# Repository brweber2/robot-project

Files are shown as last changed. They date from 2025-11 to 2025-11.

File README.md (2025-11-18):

# robot-project

Documentation for robot build out (hardware and software).

## Books

This is a mix of various open source projects and a couple of books.

* [Build Your Own Robot: Using Python, CRICKIT, and Raspberry PI](https://www.amazon.com/Build-Your-Own-Robot-Raspberry/dp/1633438457)
  * NOTE: that this project does NOT use a CRICKIT but this book is a good starting point to learn robotics concepts
* [Make: Robotic Arms](https://www.amazon.com/Make-Robotic-Arms-Matthew-Eaton/dp/1680458434)
  * code on GITHUB: https://github.com/ACBRrobotics/Make_Robotic_Arms
* [ROS 2 From Scratch](https://www.amazon.com/ROS-Scratch-started-robotics-applications/dp/B0DJCFC29Q)

## General Notes

### Utilities

* [Convert DXF files to STL](https://imagetostl.com/convert/file/dxf/to/stl)

### Tools Required

You do not need the specific tools linked, I've just included them for convenience.

* 3D Printer [FLASHFORGE Adventurer 5M](https://www.amazon.com/dp/B0CPSZ9PGS)
  * 3D Printing Slicer [Orca Slicer](https://orca-slicer.com/)
* PLA Filament [Rapid PLA Filament 1.75mm Ruby Red](https://www.amazon.com/dp/B0CB7TW3XC)
* Screwdriver [JOREST Precision Screwdriver Set](https://www.amazon.com/dp/B0D2HGJFL2)
* Heat Gun [SEEKONE Heat Gun](https://www.amazon.com/dp/B086WH19WH)
* Soldering Iron [Soldering Iron](https://www.amazon.com/gp/product/B0BX2N258S)
* M5 Hex Wrench [M5 Hex Wrench is 4mm](https://www.amazon.com/Amazon-Basics-Wrench-Standard-26-Piece/dp/B0776C2D6H)
* Soldering Mat [Soldering Mat](https://www.amazon.com/Kaisi-Insulation-Soldering-Maintenance-Electronics/dp/B073RFB6BX)

#### Software Used

* [Orca Slicer](https://orca-slicer.com/)
* [Arduino IDE](https://www.arduino.cc/en/software/)
* [ROS 2](https://www.ros.org/)

## Hardware

Much of this is from existing open source files. They are linked whenever a file was included.

### Chassis

[Chassis](CHASSIS.md)

### Wheels

[Wheels](WHEEL.md)

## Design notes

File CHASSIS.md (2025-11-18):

### Chassis

Much of this is from [Hugging Face's Lerobot](https://huggingface.co/docs/lerobot/lekiwi)

#### Non-3D Printed Parts

* Motor (3 total) [12V 37mm Motor](https://www.amazon.com/dp/B08D3SSG55)
* AWG Plug Connector [AWG Plug Connector](https://www.amazon.com/dp/B06XRBKSY2)
* Wire Heat Shrink Tubing [Wire Heat Shrink Tubing](https://www.amazon.com/dp/B0BG6V4HV4)
* Microcontroller
  * Coming soon

#### 3D Printed Parts

* Base Plate (2 total) [Base Plate](3d_prints/chassis/base_plate_layer2.stl) 
  * Source: [LeKiwi Base Plate](https://github.com/SIGRobotics-UIUC/LeKiwi/blob/main/3DPrintMeshes/base_plate_layer2.stl)
* Motor Mount (3 total) [Motor Mount](3d_prints/chassis/Marcin-61-JGB37-3650_holder.3mf) 
  * Source: [Motor Mount](https://openroboticplatform.com/part:61)
* Microcontroller Mount
  * Coming soon
* Power Source Mount
  * Coming soon

#### Assembly

Coming soon...

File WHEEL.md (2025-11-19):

### Wheels

This project uses 3 3d printed mecanum wheels.

As a starting point I used this project:
[Mecanum wheel 3d print model](https://www.thingiverse.com/thing:6175379)

#### Non-3D Printed Parts

* 693 ball bearing (24 per wheel - 72 total) (3x8x4 mm) [693 Ball Bearing](https://www.amazon.com/dp/B0DHCLF9S3)
* M3 threaded rods (12 per wheel - 36 total) 75mm long [M3 Threaded Rods](https://www.amazon.com/dp/B0D4QMWM4H)
* M3 lock nuts (24 per wheel - 72 total) [M3 Lock Nuts](https://www.amazon.com/dp/B0DFY8Y1TK)
* M3 washers (24 per wheel - 72 total) [M3 Washers](https://www.amazon.com/dp/B0B3RVM92N)
* M5 heat set threaded inserts (12 per wheel - 36 total) [M5 Heat Set Threaded Inserts](https://www.amazon.com/dp/B07YSVXWS8)
* M4 × 90mm bolts (5 per wheel - 15 total) [M4 90mm bolts](https://www.amazon.com/dp/B0DYN68HJH)
* M4 nuts (5 per wheel - 15 total) (or nylock nuts to prevent loosening) [M4 Lock Nuts](https://www.amazon.com/Vifmy-M4-0-7mm-Nuts%EF%BC%8C304-Stainless-Locknuts%EF%BC%8CStandard/dp/B0CPJCXPLJ?th=1)
* M4 washers (10 per wheel - 30 total) [M4 Washers](https://www.amazon.com/Litoexpe-Stainless-Outside-Diameter-Thickness/dp/B0BGLB6DD2)
* 20mm Heat Shrink Tubing (4 foot rolls - 2 total for 3 wheels) [Heat Shrink Tubing](https://www.amazon.com/dp/B0B616KF8J)
* M5 Screws (12 per wheel - 36 total) [M5 12mm Screws](https://www.amazon.com/iexcell-Thread-Socket-Button-Screws/dp/B0CTH2YHQ5)

#### 3D Prints

These links are the STL files. There are source files available in [3D Prints](3d_prints) if you need to make adjustments on your own.

There was no way to connect the wheel to the motor so I had Claude Code generate two adapter pieces, one for each side of the wheel. Through trial and error I found that the back plate should be 64.5mm in diameter.

Our robot is round and uses 3 wheels.

* [Rim](3d_prints/wheel/RIM.stl) 1 / wheel, 3 total.
* [Left Side](3d_prints/wheel/side_L.stl) 2 / wheel. 2 total.
  * NOTE: The STL file on thingiverse has 5 holes which does NOT match the 6 holes on the Rim and on the Right side. I've inverted the right side to make a left side with 6 holes and that is the link I provide here.
* [Right Side](3d_prints/wheel/side_R.stl) 2 / wheel. 4 total.
* [Torque Cap](3d_prints/wheel/leo_rover_torque_plate.stl) 1 / wheel. 3 total.
* [Roller](3d_prints/wheel/Roller.stl) 12 / wheel. 36 total.
  * NOTE: The original source says that if you use heat shrink tubing (which we do) you should use the thinner rollers. This lead to the frame making contact with the ground so we use heat shrink tubing on the standard rollers instead.
* [Adapter For Torque Cap Side](3d_prints/wheel/mecanum_front_plate.stl) 1 / wheel. 3 total.
* [Adapter For Back Side](3d_prints/wheel/mecanum_back_plate_64.5mm.stl) 1 / wheel. 3 total.

##### Wheel Assembly

For additional diagrams see the source project on [Thingiverse](https://www.thingiverse.com/thing:6175379)

* 3D print the parts - please note that this will take quite some time. 
  * 3 rims
  * 2 side right
  * 1 side left
  * 3 torque caps
  * 3 adapter front
  * 3 adapter back
  * 36 rollers
* Use soldering iron to put the heat set threaded inserts into the rim. Here is a helpful video on [how to use heat set threaded inserts](https://youtube.com/shorts/JnhZDiwrd0g?si=wym4r56KDjHzZoVA)
* Prepare the rollers
  * Put a 693 ball bearing in each end of the roller. I find that putting the ball bearing on the table and pushing down the roller works best to pop them into place.
  * Cut the heat shrink tubing into 36 pieces that are 55mm long
  * Wrap each roller in the heat shrink tubing
  * Use the heat gun to shrink the tubing around each roller. Do not over heat or the 3d printed roller will melt too.
* Put the wheel together (this describes the steps for ONE wheel - you will need to build THREE wheels)
  * Do this 12 times
    * Put one end of the 75mm rod through a hole in the side (left or right)
    * screw in a M3 lock nut on the outside
    * add a washer on the inside
    * slide the roller into the 75mm rod - it should fit nicely through the ball bearings in the roller
    * add a washer to the other end of the roller
  * Place the rim in the middle of the side (left or right)
  * Add a matching side piece (if using side right then side right, if using side left the another side left)
    * Do this 12 times
      * one roller at a time pass the rod through a whole in the side
      * add a M3 lock nut
  * secure the rim to the sides using M5 12mm screws. Be sure to secure it to both sides.
  * slide the torque cap into the rim (it will only fit on the side with grooves)
  * Use the 90mm bolts and M4 lock nuts to fasten the front adapter to the torque cap and the back adapter (which goes on the opposite side as the torque cap). The front adapter has a hole in the middle for the motor's d-shaft and is smaller in diameter than the back adapter.
  I put the nuts in the back adapter and the bolts through the front adapter. Once the bolts are in the recessed holes in the front adapter use a M4 allen wrench to tighten them.

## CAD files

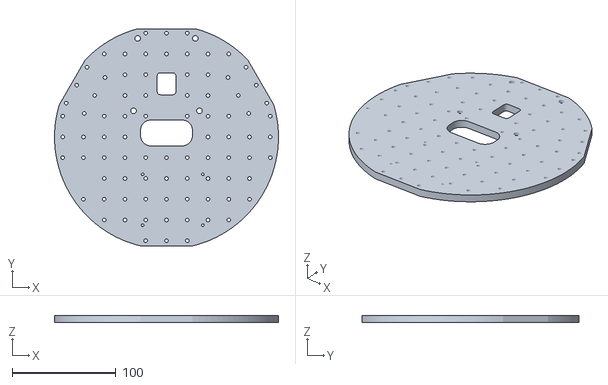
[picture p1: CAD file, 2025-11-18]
3d_prints/chassis/base_plate_layer2.stl
215.9 x 209.0 x 7.00

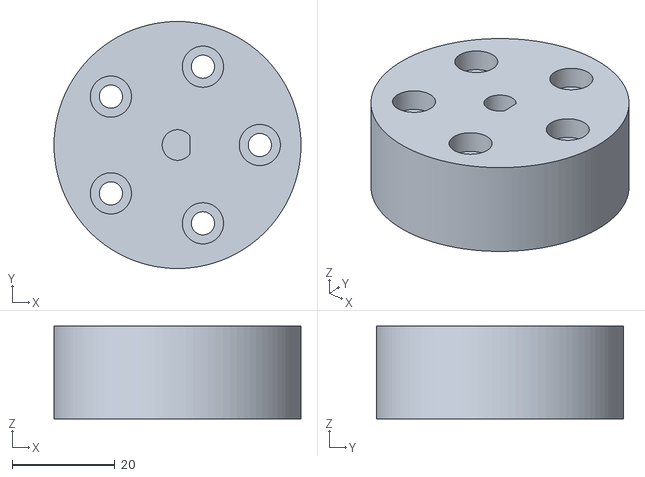
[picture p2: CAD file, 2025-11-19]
3d_prints/wheel/mecanum_front_plate.stl
48.0 x 48.0 x 18.0

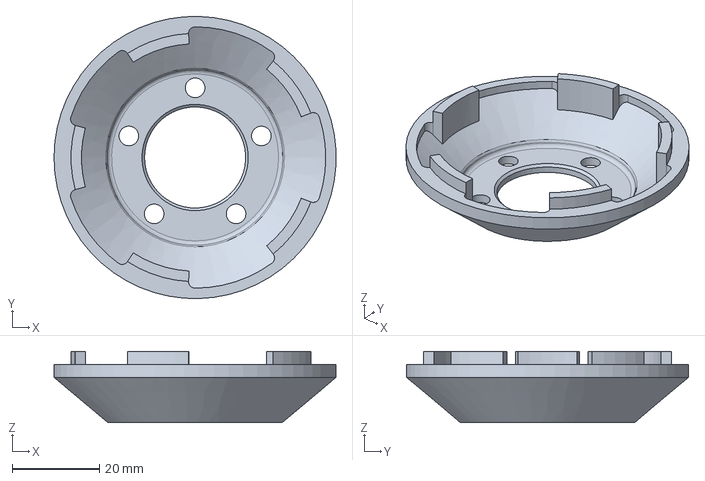
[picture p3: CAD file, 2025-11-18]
3d_prints/wheel/leo_rover_torque_plate.step
64.8 x 64.8 x 16.4 mm

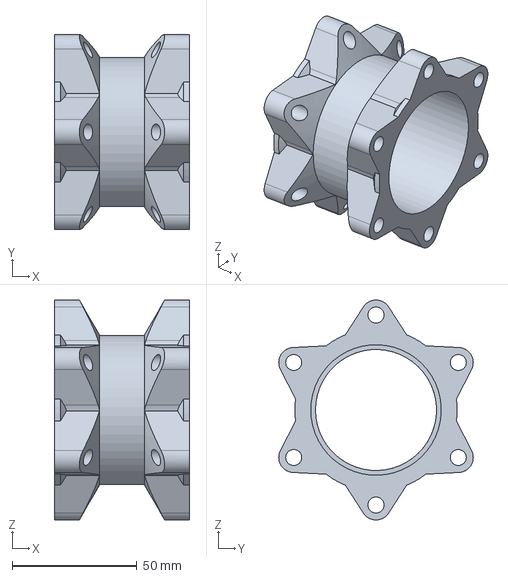
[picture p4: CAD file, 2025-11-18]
3d_prints/wheel/rim.step
54.1 x 77.8 x 88.0 mm

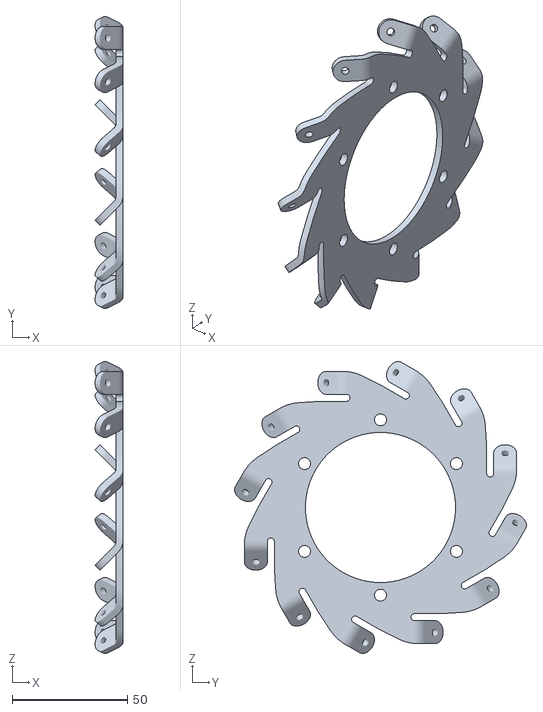
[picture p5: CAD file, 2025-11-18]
3d_prints/wheel/side_L.stl
12.1 x 126.5 x 126.5

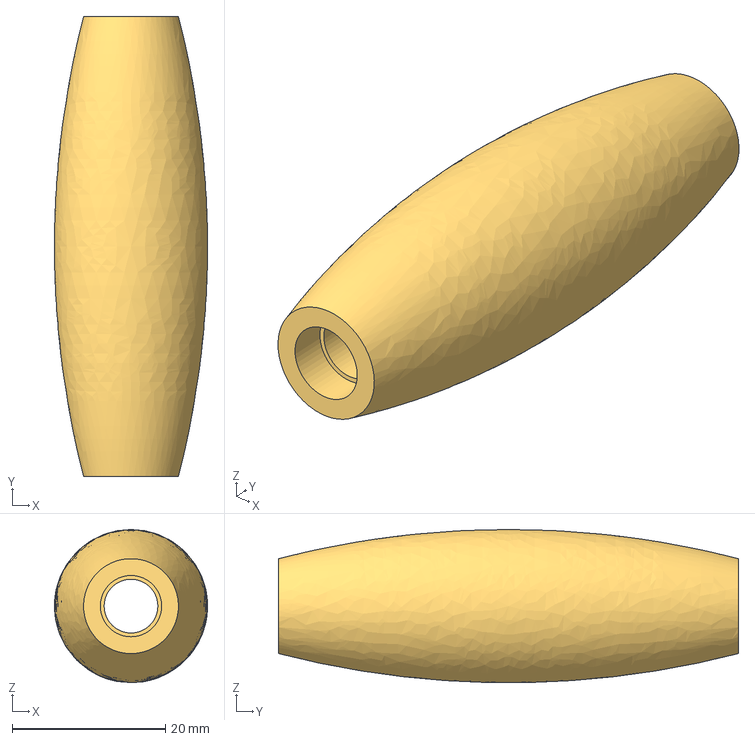
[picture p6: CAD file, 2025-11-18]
3d_prints/wheel/Roller.step
20.0 x 60.0 x 20.0 mm

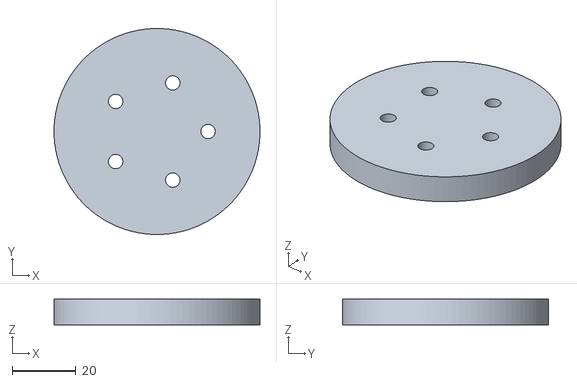
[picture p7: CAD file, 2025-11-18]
3d_prints/wheel/mecanum_back_plate_64.5mm.stl
64.5 x 64.5 x 8.00

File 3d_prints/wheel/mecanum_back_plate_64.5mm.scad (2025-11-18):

// Back Plate for Mecanum Wheel Motor Adapter
// Opposite side from motor - 64.5mm diameter version

$fn = 100; // Smooth circles

// Parameters
outer_diameter = 64.5;
plate_thickness = 8;
bolt_circle_diameter = 32;
bolt_hole_diameter = 4.5; // M4 clearance
nut_recess_diameter = 8; // M4 hex nut recess (7mm + tolerance)
nut_recess_depth = 4; // M4 nut thickness + tolerance
num_holes = 5;

module back_plate() {
    difference() {
        // Main cylinder
        cylinder(h = plate_thickness, d = outer_diameter);
        
        // M4 bolt holes on bolt circle with nut recesses
        for (i = [0:num_holes-1]) {
            angle = i * 360 / num_holes;
            rotate([0, 0, angle]) {
                translate([bolt_circle_diameter/2, 0, -0.5]) {
                    // Through hole for bolt
                    cylinder(h = plate_thickness + 1, d = bolt_hole_diameter);
                    // Hex nut recess on bottom
                    translate([0, 0, -0.5])
                        cylinder(h = nut_recess_depth + 0.5, d = nut_recess_diameter, $fn = 6);
                }
            }
        }
    }
}

back_plate();

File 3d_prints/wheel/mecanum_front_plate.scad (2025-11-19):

// Front Plate for Mecanum Wheel Motor Adapter
// Motor side with D-shaft bore

$fn = 100; // Smooth circles

// Parameters
outer_diameter = 48;
plate_thickness = 18;
d_shaft_diameter = 5.95; // Slightly undersized for press fit
d_shaft_depth = 15;
d_flat_depth = 0.5; // How much to cut off for D-shape
bolt_circle_diameter = 32;
bolt_hole_diameter = 4.5; // M4 clearance
screw_head_recess_diameter = 8; // M4 screw head recess
screw_head_recess_depth = 4; // M4 screw head depth + tolerance
num_holes = 5;

module front_plate() {
    difference() {
        // Main cylinder
        cylinder(h = plate_thickness, d = outer_diameter);
        
        // D-shaft bore
        translate([0, 0, plate_thickness - d_shaft_depth]) {
            difference() {
                cylinder(h = d_shaft_depth + 0.1, d = d_shaft_diameter);
                // D-flat cutout
                translate([d_shaft_diameter/2 - d_flat_depth, -d_shaft_diameter/2, -0.05])
                    cube([d_flat_depth + 1, d_shaft_diameter, d_shaft_depth + 0.2]);
            }
        }
        
        // M4 bolt holes on bolt circle
        for (i = [0:num_holes-1]) {
            angle = i * 360 / num_holes;
            rotate([0, 0, angle])
                translate([bolt_circle_diameter/2, 0, -0.5]) {
                    // Through hole for bolt
                    cylinder(h = plate_thickness + 1, d = bolt_hole_diameter);
                    // Screw head recess on same side as D-shaft (top of plate)
                    translate([0, 0, plate_thickness - screw_head_recess_depth + 0.5])
                        cylinder(h = screw_head_recess_depth + 0.5, d = screw_head_recess_diameter);
                }
        }
    }
}

front_plate();

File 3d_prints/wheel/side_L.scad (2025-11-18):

// Mirror Side R to create Side L with 6 holes
// This mirrors the design so the flaps go in the opposite direction

// Import the right side STL
module side_r() {
    import("/mnt/user-data/uploads/side_R.stl");
}

// Mirror along Y-axis to reverse the flap direction (left-right mirror)
mirror([0, 1, 0]) {
    side_r();
}

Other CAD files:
3d_prints/wheel/side_R.step
3d_prints/chassis/Marcin-61-JGB37-3650_holder.3mf
3d_prints/wheel/RIM.stl
3d_prints/wheel/Roller.stl
3d_prints/wheel/leo_rover_torque_plate.stl
3d_prints/wheel/side_R.stl

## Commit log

2025-11-18 saving instructions for wheels and start of chassis
    [Marcin-61-JGB37-3650_holder.3mf, Marcin-61-JGB37-3650_holder.step, RIM.stl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]
2025-11-18 fixing case sensitive file name
2025-11-19 uploading improved front adapter files
    [mecanum_front_plate.scad, mecanum_front_plate.stl]
